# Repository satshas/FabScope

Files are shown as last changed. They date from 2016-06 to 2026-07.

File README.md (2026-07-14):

# Fab Scope

An easily fabbable and portable oscilloscope.

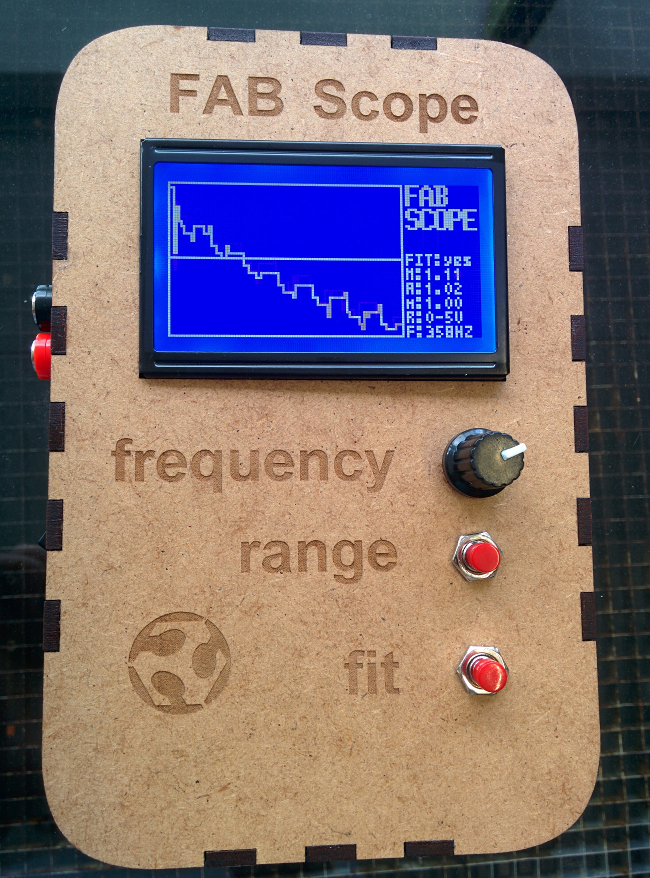
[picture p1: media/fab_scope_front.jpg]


Features
--

- 2 voltage range supported: 0-5V, 0-50V (DC only)
- button to change the voltage ranges and fit using interrupts
- supported sampling frequency: from 100HZ to 10KHZ
- adjustable sampling frequency using a potentiometer
- 128 x 64 graphic display
- embedded high voltage relays
- on/off switch
- plug and play probes
- portable (9V battery last for more than 8 hours)
- mdf and acrylic cases
- programmable using an FTDI
- voltage measurements: max, min, average
- fit function that will zoom exactly into the current signal range

Board
--

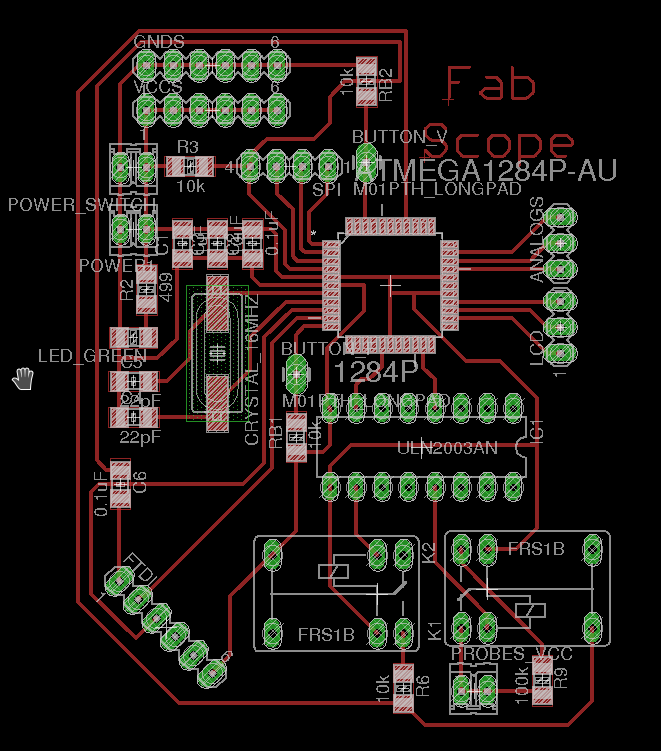
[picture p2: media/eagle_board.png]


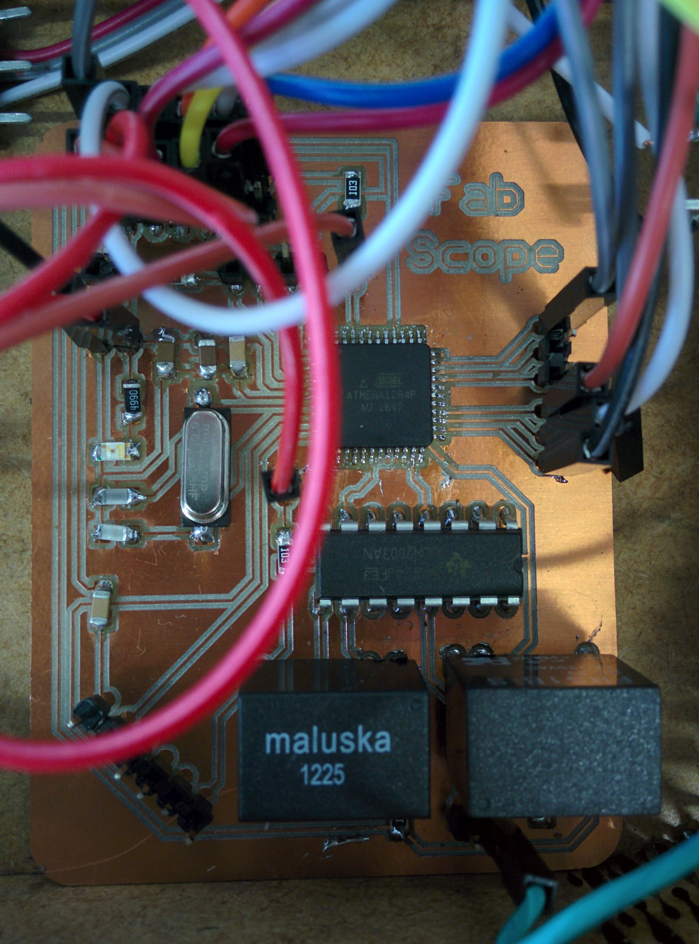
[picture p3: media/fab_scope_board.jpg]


- [Fab12 scope schematic](https://github.com/satshas/FabScope/raw/master/eagle/fab_scope.sch)
- [Fab12 scope board](https://github.com/satshas/FabScope/raw/master/eagle/fab_scope.brd)
- [Fab12 scope internal png](https://github.com/satshas/FabScope/raw/master/media/fab_scope_internal.png)
- [Fab12 scope cut png](https://github.com/satshas/FabScope/raw/master/media/fab_scope_cut.png)

Software
--

[download the code](https://raw.githubusercontent.com/satshas/FabScope/master/code/fab_scope/fab_scope.ino)

Media
--

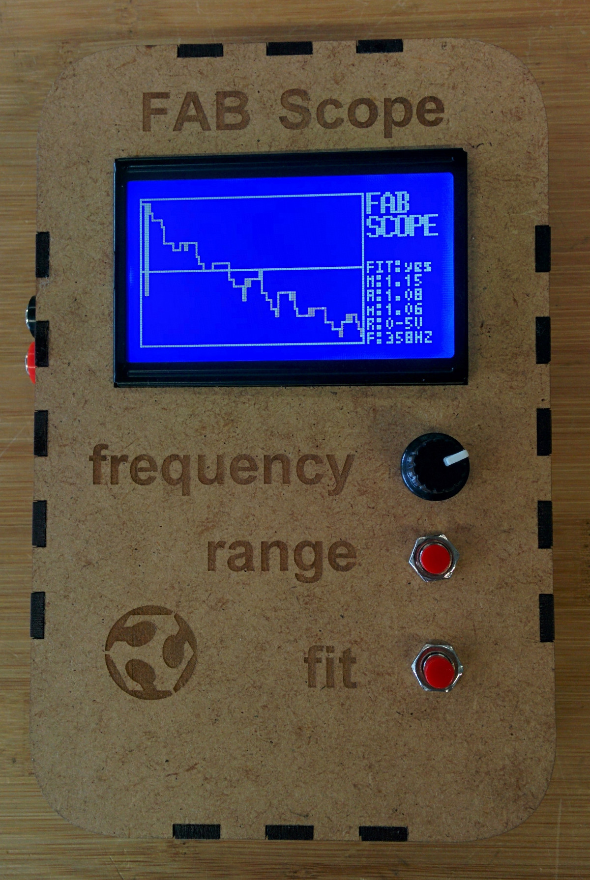
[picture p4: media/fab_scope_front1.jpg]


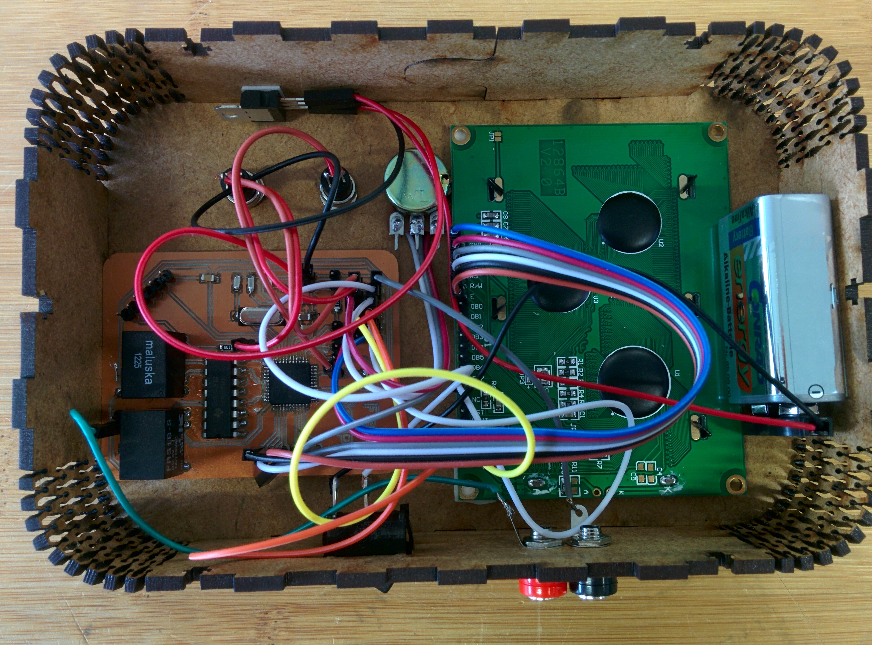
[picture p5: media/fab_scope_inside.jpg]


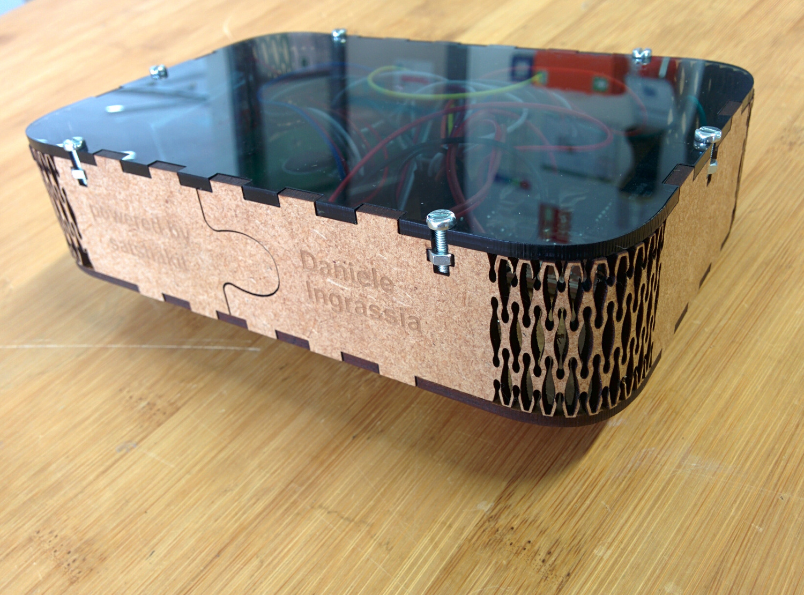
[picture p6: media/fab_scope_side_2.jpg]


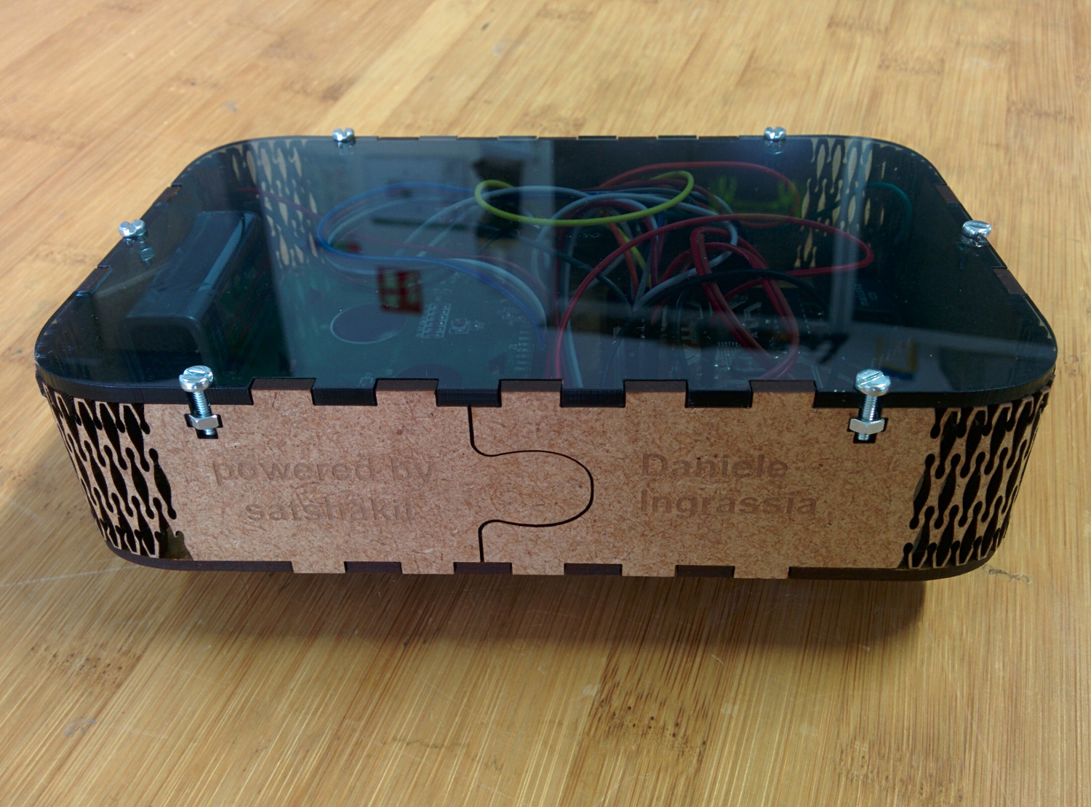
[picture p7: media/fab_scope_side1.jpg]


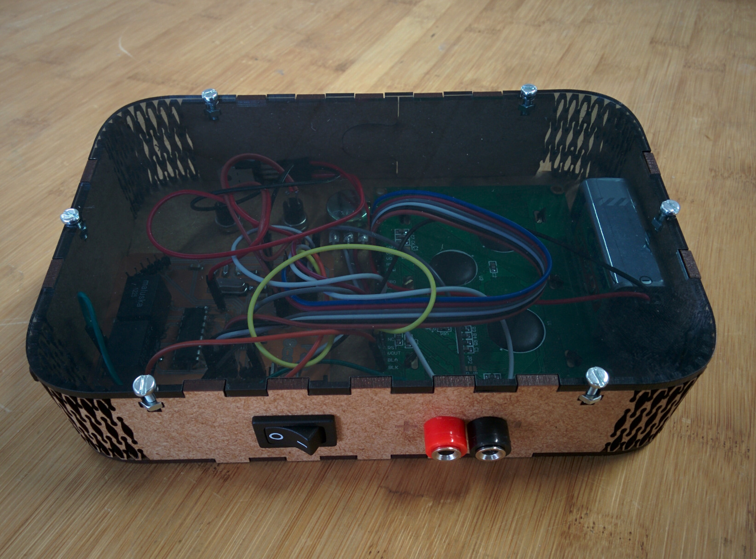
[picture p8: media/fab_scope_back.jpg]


Authors
--

- Daniele Ingrassia

Contact
--

- **ingrassiada@gmail.com**
- **[linkedin](http://it.linkedin.com/in/danieleingrassia)**

Thanks
--

[Fablab Kamp-Lintfort](http://fablab.hochschule-rhein-waal.de/index.php/de/)<br />
Hochschule Rhein-Waal<br />
Friedrich-Heinrich-Allee 25, 47475 Kamp-Lintfort, Germany<br />
fablab@hochschule-rhein-waal.de

License
--
This work is licensed under the terms of Attribution-ShareAlike 4.0 International ([CC BY-SA 4.0](https://creativecommons.org/licenses/by-sa/4.0/)).

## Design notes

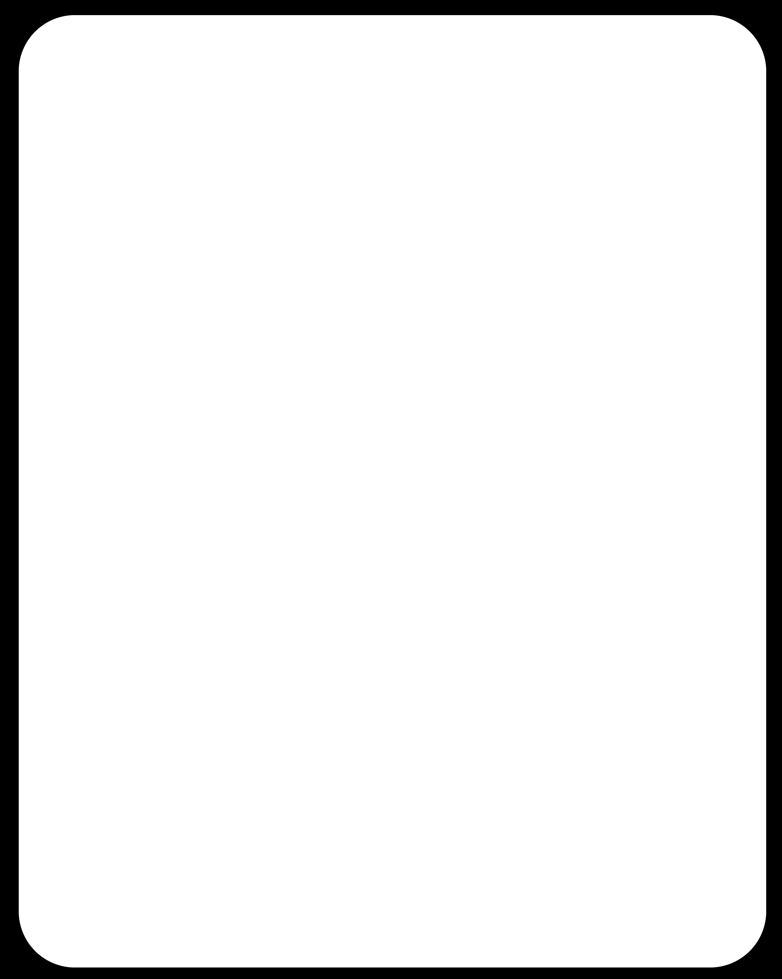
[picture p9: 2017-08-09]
media/fab_scope_cut.png

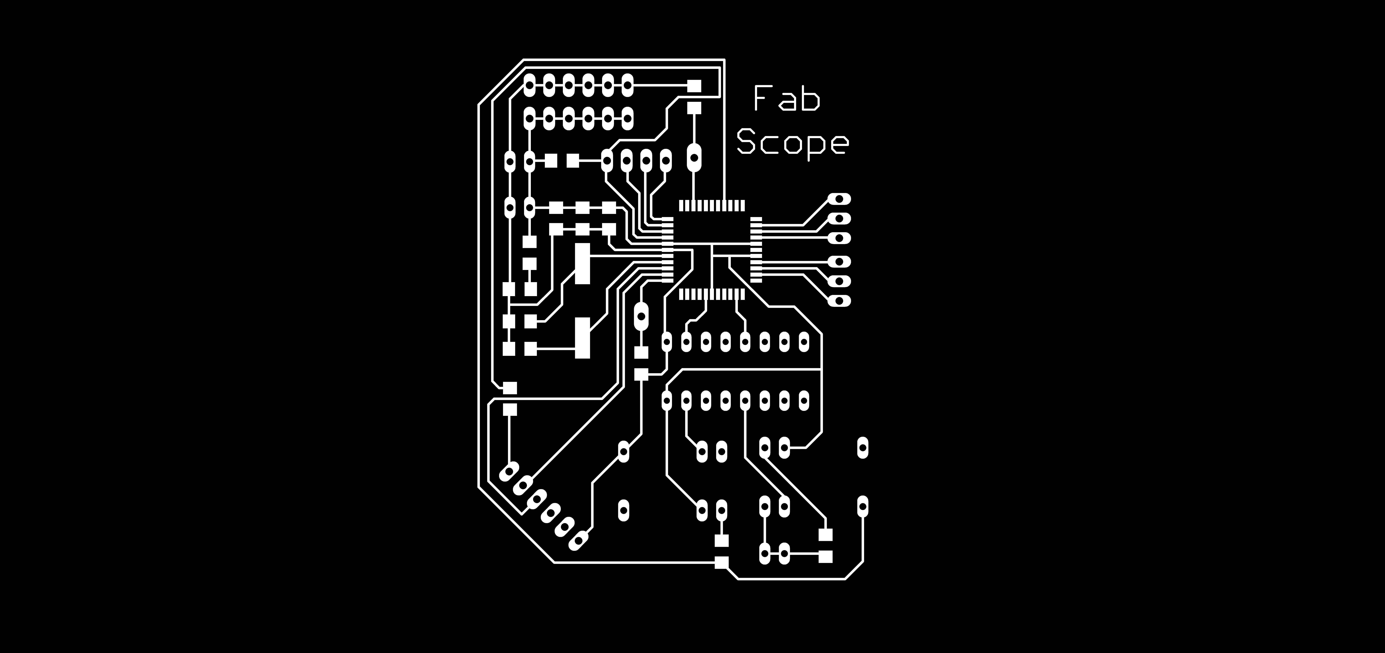
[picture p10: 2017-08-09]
media/fab_scope_all.png

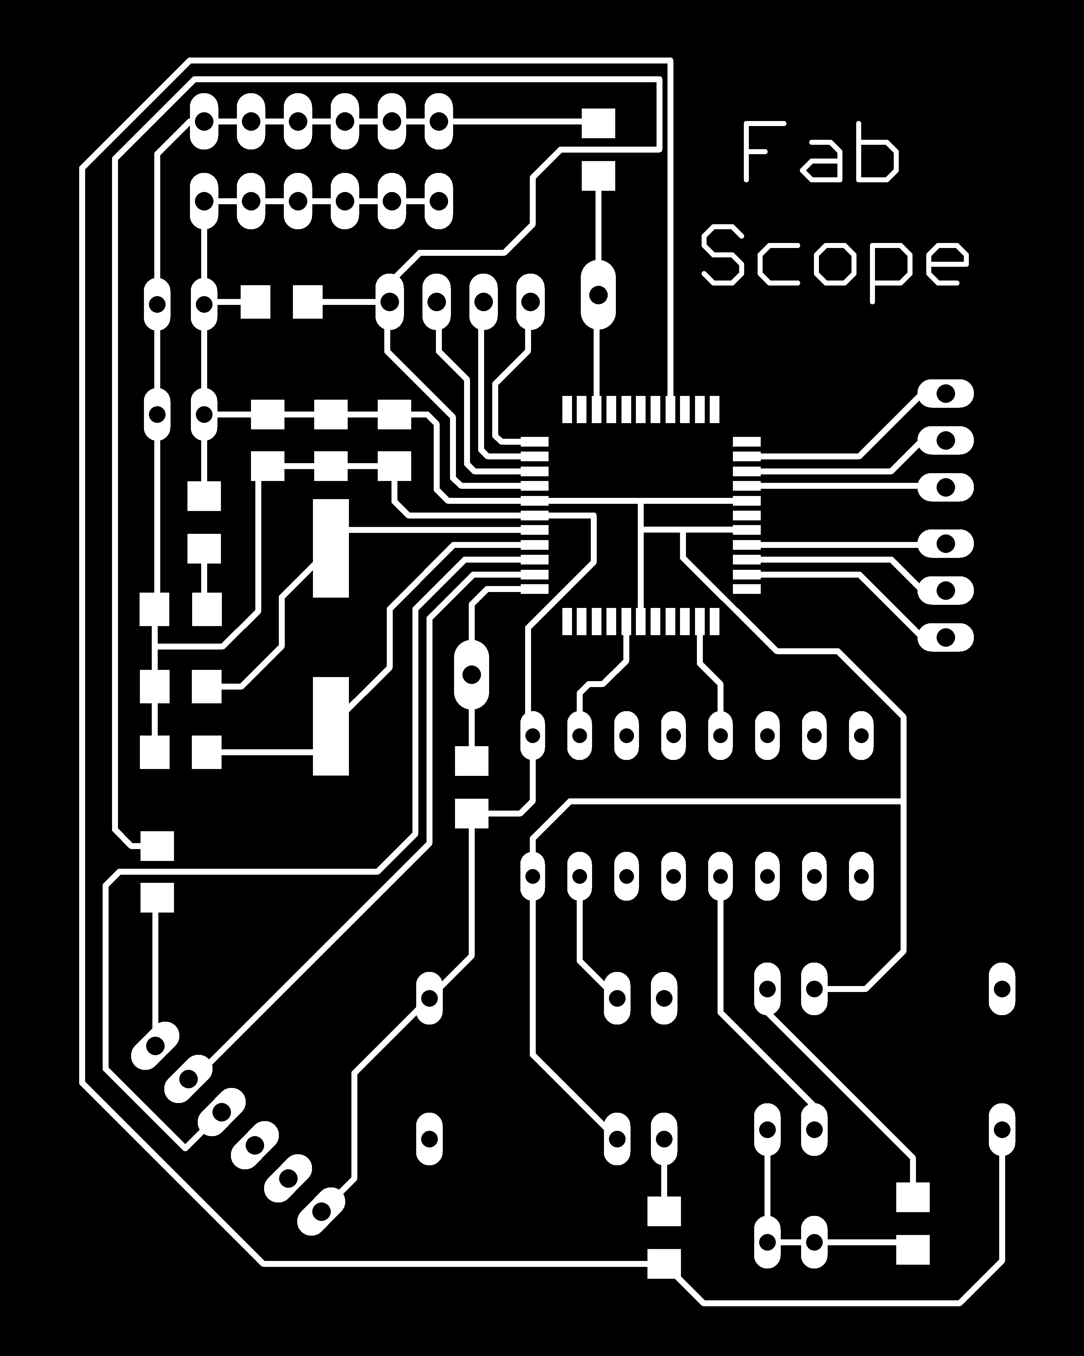
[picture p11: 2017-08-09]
media/fab_scope_internal.png

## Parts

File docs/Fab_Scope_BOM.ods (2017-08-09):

Value | Manufacturer Part No | Package | Description | FARNELL | Price € | Quantity | Min. Quantity Cost €
- | ATMEGA1284P-AU | TQFP-44 | microcontroller | Aliexpress (http://it.farnell.com/atmel/atmega1284p-au/mcu-8bit-atmega-20mhz-tqfp-44/dp/1715480) | 3.47 | 1 | 3.47
16Mhz/18pF | MCRSD16000F183000RR | SMD 11.4 x 4.7 mm | crystal | FARNELL (http://it.farnell.com/multicomp/mcrsd16000f183000rr/crystal-16mhz-18pf-hc49-us-smd/dp/2395958) | 0.20 | 1 | 0.20
10K | ERJ8GEYJ103V | 1206 | resistor | FARNELL (http://it.farnell.com/panasonic-electronic-components/erj8geyj103v/resistore-1206-10k-5-0-25w/dp/2057856) | 0.03 | 8 | 0.26
22pF | MC1206N220J500CT | 1206 | capacitor | FARNELL (http://it.farnell.com/multicomp/mc1206n220j500ct/condens-mlcc-c0g-np0-22pf-50v/dp/2320891) | 0.05 | 2 | 0.47
10uF | MC1206X106K250CT | 1206 | capacitor | FARNELL (http://it.farnell.com/multicomp/mc1206x106k250ct/condensatore-mlcc-x5r-10uf-25v/dp/2112753) | 0.15 | 1 | 0.15
1uF | MC1206F105Z500CT | 1206 | capacitor | FARNELL (http://it.farnell.com/multicomp/mc1206f105z500ct/condensatore-mlcc-y5v-1uf-50v/dp/1759455) | 0.06 | 1 | 0.63
100nF | MC1206B104K500CT | 1206 | capacitor | FARNELL (http://it.farnell.com/multicomp/mc1206b104k500ct/condensatore-mlcc-x7r-100nf-50v/dp/1759361) | 0.04 | 2 | 0.35
green | MCL-S250GC | 1206 | green led | FARNELL (http://it.farnell.com/multicomp/mcl-s250gc/led-smd-1206-verde/dp/1581232) | 0.12 | 1 | 0.60
499 | CRCW1206499RFKEA | 1206 | resistor | FARNELL (http://it.farnell.com/vishay-draloric/crcw1206499rfkea/resistor-1206-499r-1/dp/1470020) | 0.03 | 1 | 0.28
100k | MC0125W12061100K | 1206 | resistor | FARNELL (http://it.farnell.com/multicomp/mc0125w12061100k/res-film-spesso-100k-1-0-125w/dp/9335773) | 0.0035 | 1 | 0.04
499k | MC0063W06031499K | 1206 | resistor | FARNELL (http://it.farnell.com/multicomp/mc0063w06031499k/res-film-spesso-499k-1-0-063w/dp/1171055) | 0.0013 | 2 | 0.01
pin header | 61304011021 | 2.54 mm | pin header | FARNELL (http://it.farnell.com/wurth-elektronik/61304011021/header-2-54mm-pin-tht-r-a-40way/dp/2356192) | 1.77 | 1 | 1.77
pin header | M20-9990246 | 2.54 mm | pin header | FARNELL (http://it.farnell.com/harwin/m20-9990246/header-diritta-2-54mm-1row-bifase/dp/1022247) | 0.07 | 2 | 0.65
LCD display | 12864 V2.0 | - | LCD display | Aliexpress (https://www.aliexpress.com/item/128-64-DOTS-LCD-module-5V-blue-screen-12864-LCD-with-backlight-ST7920-Parallel-port/32464276214.html) | 5.53 | 1 | 5.53
driver | ULN2003A | - | darlington array | FARNELL (http://it.farnell.com/stmicroelectronics/uln2003a/darlington-array-7npn-2003-dip16/dp/1094421) | 0.52 | 1 | 0.52
relay | FRS1B-S | - | 5V relay | EBAY (http://www.ebay.de/itm/Relais-MALUSKA-FRS1B-S-24-V-1-Wechsler-340570-/142289295972) | 1 | 2 | 2
push button | SPST-NO Button | - | SPST-NO push button | EBAY (http://www.ebay.it/itm/251383502767?var=550311934053&ssPageName=STRK%3AMEBIDX%3AIT) | 1.19 | 2 | 2.38
10k | B10K |  | 10K potentiometer | EBAY (http://www.ebay.de/itm/1x-Lineares-Drehpotentiometer-10-k-Potentiometer-Potenziometer-B10K-/292161587681) | 2 | 1 | 2
MDF | - | - | 3mm MDF wood (50x70cm) | - | - | - | -
acrylic | - | - | 3mm acrylic (15x20cm) | - | - | - | -
wires | - | - | various 0.14mm wires | - | - | - | -
double side scotch tape |  |  | double side mounting scotch tape | - | - | - | -
nuts and bolts |  |  | 6xM3 10mm and 6xM3 nuts | - | - | - | -
5V voltage reg | 7805 |  | step up/step down voltage regulator | FARNELL (http://de.farnell.com/fairchild-semiconductor/lm7805ct/v-reg-5-0v-7805-to-220-3/dp/1696994) | 0.658 | 1 | 0.658
banana plug | - | - | banana plug | HOBBY KING (http://www.hobbyking.com/hobbyking/store/__74597__XT30_charge_lead_with_4mm_banana_plugs_AR_Warehouse_.html) | 1.91 | 1 | 1.91
FR2/FR4 copper sheet | - | - | single side 100x160mm | - | - | 1 | -
cyanoacrylate glue | - | - | standard cyano glue (SuperGlue/Attack) | - | - | - | -
 |  |  |  |  |  |  | Total cost
 |  |  |  |  |  |  | 23.886

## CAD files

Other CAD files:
design/Fab_Scope.3dm

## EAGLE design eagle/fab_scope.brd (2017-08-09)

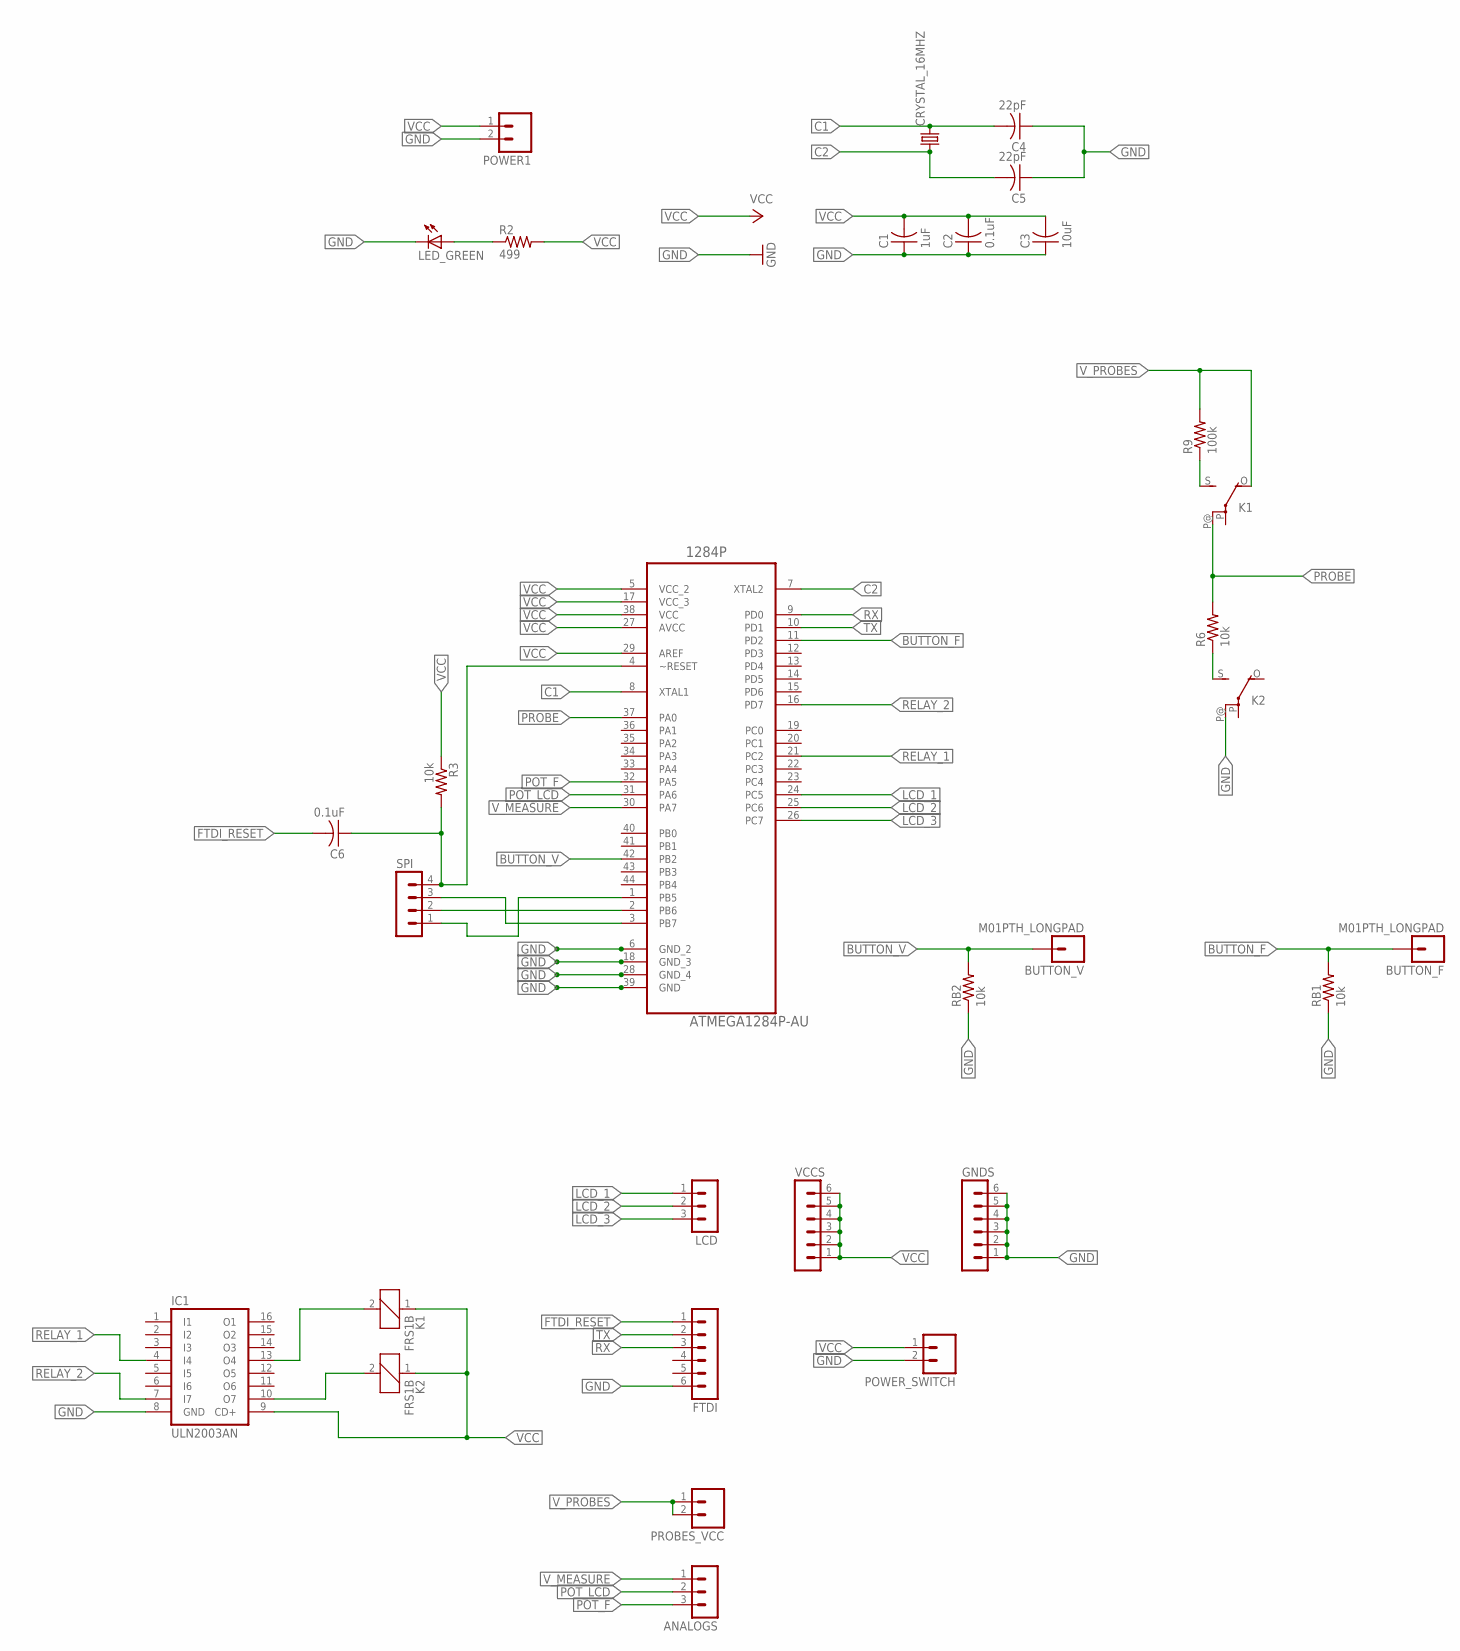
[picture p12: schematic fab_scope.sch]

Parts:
1284P: ATMEGA1284P-AU; QFP80P1200X1200X120-44N
ANALOGS: MA03-1
BUTTON_F: M01PTH_LONGPAD; 1X01_LONGPAD
BUTTON_V: M01PTH_LONGPAD; 1X01_LONGPAD
C1: 1uF; C1206
C2, C6: 0.1uF; C1206
C3: 10uF; C1206
C4, C5: 22pF; C1206
CRYSTAL_16MHZ: CRYSTALHC49UP; HC49UP
FTDI: MA06-1
GNDS: MA06-1
IC1: ULN2003AN; DIL16
K1, K2: FRS1B
LCD: MA03-1
LED_GREEN: LED1206; 1206
POWER1: M02; 02P
POWER_SWITCH: M02; 02P
PROBES_VCC: M02; 02P
R2: 499; R1206
R3, R6: 10k; R1206
R9: 100k; R1206
RB1, RB2: 10k; R1206
SPI: MA04-1
VCCS: MA06-1

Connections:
BUTTON_F: 1284P.11 (PD2), BUTTON_F.1, RB1.2
BUTTON_V: 1284P.42 (PB2), BUTTON_V.1, RB2.2
C1: 1284P.8 (XTAL1), C4.2, CRYSTAL_16MHZ.2
C2: 1284P.7 (XTAL2), C5.2, CRYSTAL_16MHZ.1
FTDI_RESET: C6.2, FTDI.1
GND: 1284P.6 (GND_2), C1.1, C2.1, C3.1, C4.1, C5.1, FTDI.6, GNDS.1, GNDS.2, GNDS.3, GNDS.4, GNDS.5, GNDS.6, IC1.8 (GND), K2.P@, LED_GREEN.2 (C), POWER1.2, POWER_SWITCH.2, RB1.1, RB2.1
LCD_1: 1284P.24 (PC5), LCD.1
LCD_2: 1284P.25 (PC6), LCD.2
LCD_3: 1284P.26 (PC7), LCD.3
unnamed: IC1.10 (O7), K2.2
unnamed: IC1.13 (O4), K1.2
unnamed: K2.S, R6.1
unnamed: K1.S, R9.1
unnamed: 1284P.3 (PB7), SPI.3
unnamed: 1284P.2 (PB6), SPI.2
unnamed: 1284P.1 (PB5), SPI.1
unnamed: 1284P.4 (~RESET), C6.1, R3.2, SPI.4
unnamed: LED_GREEN.1 (A), R2.1
POT_F: 1284P.32 (PA5), ANALOGS.3
POT_LCD: 1284P.31 (PA6), ANALOGS.2
PROBE: 1284P.37 (PA0), K1.P@, R6.2
RELAY_1: 1284P.21 (PC2), IC1.4 (I4)
RELAY_2: 1284P.16 (PD7), IC1.7 (I7)
RX: 1284P.9 (PD0), FTDI.3
TX: 1284P.10 (PD1), FTDI.2
VCC: 1284P.5 (VCC_2), 1284P.17 (VCC_3), 1284P.27 (AVCC), 1284P.29 (AREF), C1.2, C2.2, C3.2, IC1.9 (CD+), K1.1, K2.1, POWER1.1, POWER_SWITCH.1, R2.2, R3.1, VCCS.1, VCCS.2, VCCS.3, VCCS.4, VCCS.5, VCCS.6
V_MEASURE: 1284P.30 (PA7), ANALOGS.1
V_PROBES: K1.O, PROBES_VCC.1, PROBES_VCC.2, R9.2

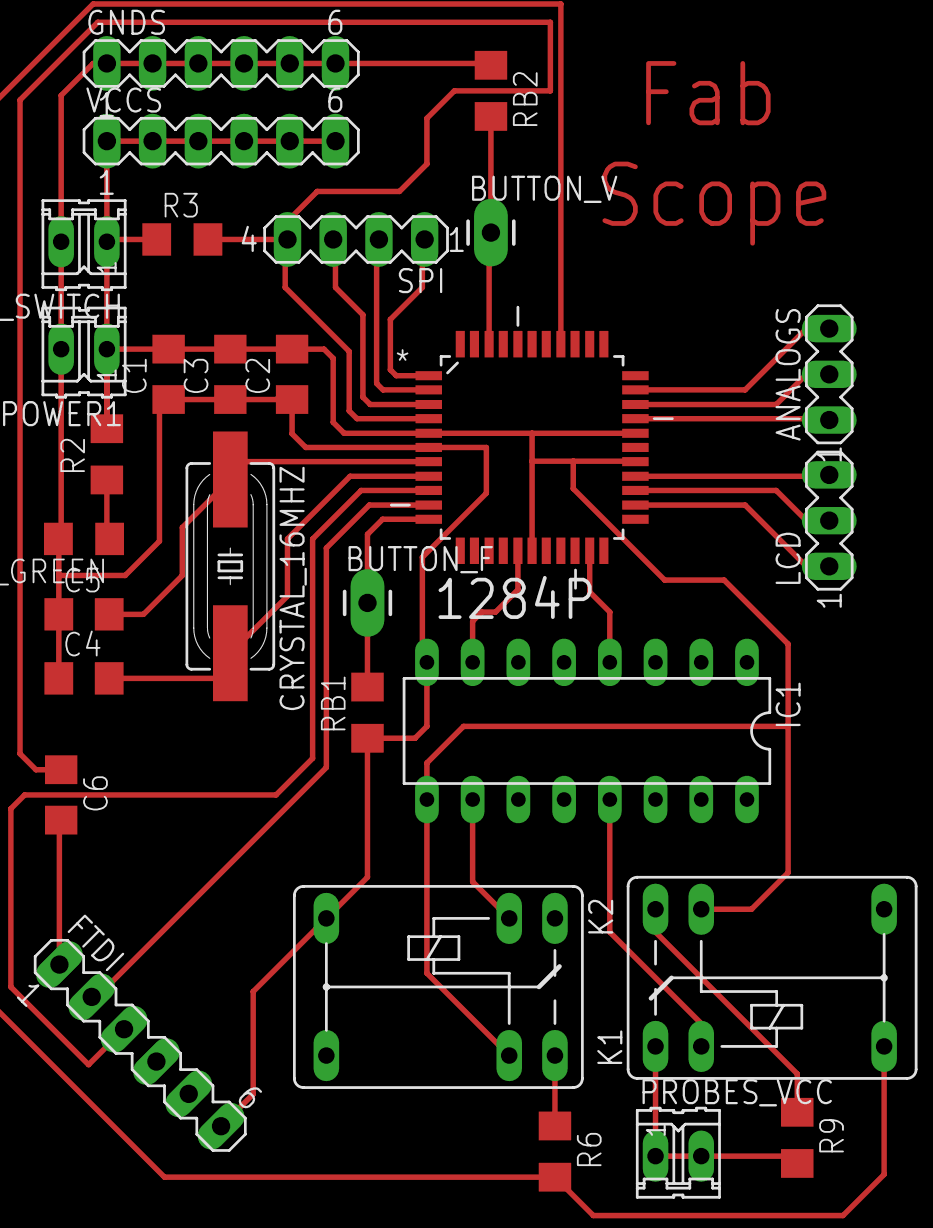
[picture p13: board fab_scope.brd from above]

Board: 2 copper layers, 29 parts (0 on the bottom side), 28 nets.

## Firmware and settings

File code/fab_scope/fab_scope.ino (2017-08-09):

#include "U8glib.h"

#define SIGNAL_FRAME_H 64
#define SIGNAL_FRAME_W 96
#define SIGNAL_FRAME_PROBED 94
#define PROBE_PIN A0
#define SAMPLING_RATE_PIN A5
#define BUTTON_VOLTAGE_RANGE 2
#define BUTTON_FIT 10

#define RELAY_K1_PIN 15
#define RELAY_K2_PIN 18

//#define RELAY_K3_PIN 15
//#define RELAY_K4_PIN 16
//#define RELAY_K5_PIN 17
//#define RELAY_K6_PIN 18

#define MINIMUM_DISPLAY_SIGNAL_HEIGHT 3
#define MAXIMUM_DISPLAY_SIGNAL_HEIGHT 61

uint16_t minimumAnalogRead;
uint16_t maximumAnalogRead;

#define MINIMUM_ANALOG_READ 0
#define MAXIMUM_ANALOG_READ 1023

#define BUTTON_RANGE_TIME_PRESS_AGAIN 1000

//#define SAMPLING_RATE_MAX_MICROSECONDS 100000
#define SAMPLING_RATE_MAX_MICROSECONDS 10000
#define SAMPLING_RATE_MIN_MICROSECONDS 100

const bool DEBUG  = true;

char freqPrint[9];
char voltagePrint[8];
char voltageRangePrint[9];
bool fitFunction;
long probeRate;
float probeRateMillis;
uint16_t probe1Valuea, maxVoltageProbe, minVoltageProbe;
long avgVoltageProbe;
uint16_t probedValues[SIGNAL_FRAME_PROBED];
uint8_t C,Z,probedValuesCounter;
uint8_t currentRange;
long buttonRangeTimePressed1,buttonRangeTimePressed2;
double samplingFrequency;
double maxVoltage,minVoltage,avgVoltage;
double currentVoltageRatio;
const double voltageRatio5 = 0.00497512437811; //volts per unit
const double voltageRatio50 = 0.05681818181818;//volts per unit
const double voltageRatio120 = 0.15151515151515;//volts per unit
const double voltageRatio200 = 0.38461538461538;//volts per unit

U8GLIB_ST7920_128X64 u8g(23, 21, 22, U8G_PIN_NONE);

void setup(void) {
  
  //debug init
   if(DEBUG)
    Serial.begin(9600);

  fitFunction = false;
  minimumAnalogRead = 0;
  maximumAnalogRead = 1023;
    
  //analog input init
  pinMode(PROBE_PIN,INPUT);
  pinMode(SAMPLING_RATE_PIN,INPUT);

  //digital relay pins init
  pinMode(RELAY_K1_PIN,OUTPUT);
  pinMode(RELAY_K2_PIN,OUTPUT);
  //pinMode(RELAY_K3_PIN,OUTPUT);
  //pinMode(RELAY_K4_PIN,OUTPUT);
  //pinMode(RELAY_K5_PIN,OUTPUT);
  //pinMode(RELAY_K6_PIN,OUTPUT);

  //init time vars
  buttonRangeTimePressed1 = 0;
  buttonRangeTimePressed2 = 0;

  //digital button pin inputs
  pinMode(BUTTON_VOLTAGE_RANGE,INPUT);
  pinMode(BUTTON_FIT,INPUT);
 
  //other settings & init
  probeRate = 20;
  probedValuesCounter = 0;
   
  //display init
  u8g.setColorIndex(1);

  //default position at maximum voltage
  switch_5();

  //attach interrupts for changing the voltage range
  attachInterrupt(digitalPinToInterrupt(BUTTON_VOLTAGE_RANGE), interruptFunctionRange, HIGH);

  //attach interrupts for changing the fit button
  attachInterrupt(digitalPinToInterrupt(BUTTON_FIT), interruptFunctionFit, HIGH);
 
  if(DEBUG)
    Serial.println("init ok");
 
}

void loop(void) {

  /*if(digitalRead(BUTTON_FIT)){

    if(DEBUG)
      Serial.println("buttonFit");

      if(fitFunction)
        fitFunction = false;
    else
      fitFunction = true;
    
  }*/
  
  //do a complete probe and then refresh the screen
  //this is needed because the resfresh rate of the display is to slow

  //first calculate the probe rate according to the position of the potentiometer
  probeRate = analogRead(SAMPLING_RATE_PIN);
  probeRate = map(probeRate,MINIMUM_ANALOG_READ,MAXIMUM_ANALOG_READ,SAMPLING_RATE_MIN_MICROSECONDS,SAMPLING_RATE_MAX_MICROSECONDS);
  samplingFrequency = probeRate;
  probeRateMillis = probeRate/1000;
  samplingFrequency = 1/(samplingFrequency*0.000001);
 
  if(DEBUG)
    Serial.println(samplingFrequency);

  //now start to fill the data buffer with samples
  //reset the voltage statistics
  maxVoltageProbe = 0;
  minVoltageProbe=1500;
  avgVoltageProbe = 0;
  
  Z=0;
  
  while(true){

      //place this inside an interrupt or outside the for
      //of just simplyfy the loop and consider the time of the analog read
      probedValues[Z] = analogRead(PROBE_PIN);
        
      //wait a certain amount of time according to the sampling rate
      if(probeRate<1000 && probeRate>=SAMPLING_RATE_MIN_MICROSECONDS)
        delayMicroseconds(probeRate-100);//consider the analog read
      else
        delay(probeRateMillis);//here not consider the analogRead delay

        ++Z;
        if(Z==SIGNAL_FRAME_PROBED)
          break;
           
  }

  //read only the voltage statistics
  Z=0;
  
  for(;Z<SIGNAL_FRAME_PROBED;Z++){
            
      //do statistics about the voltage
      
      if(probedValues[Z] > maxVoltageProbe)
        maxVoltageProbe = probedValues[Z];
      
      if( probedValues[Z] < minVoltageProbe)
        minVoltageProbe = probedValues[Z];

      avgVoltageProbe += probedValues[Z];
          
  }

  //check the fit function
  if(fitFunction){

    minimumAnalogRead = minVoltageProbe;
    maximumAnalogRead = maxVoltageProbe;
    
  }else{

   minimumAnalogRead = MINIMUM_ANALOG_READ;
   maximumAnalogRead = MAXIMUM_ANALOG_READ;
    
  }

  Z=0;
  
  for(;Z<SIGNAL_FRAME_PROBED;Z++)          
      probedValues[Z] = map(probedValues[Z],minimumAnalogRead,maximumAnalogRead,MINIMUM_DISPLAY_SIGNAL_HEIGHT,MAXIMUM_DISPLAY_SIGNAL_HEIGHT);
          
  if(DEBUG){

      Serial.print("max probe: ");
      Serial.println(maxVoltageProbe);
      Serial.print("min probe: ");
      Serial.println(minVoltageProbe);
      Serial.print("voltage ratio: ");
      Serial.println(currentVoltageRatio,15);

      Serial.print("avg sum: ");
      Serial.println(avgVoltageProbe);
     
  }

  //depends on the range selected you can have different ratio to obtain the real voltages values
  maxVoltage = currentVoltageRatio*maxVoltageProbe;
  minVoltage = currentVoltageRatio*minVoltageProbe;
  avgVoltage = currentVoltageRatio*avgVoltageProbe;

  //here divide to have the average
  avgVoltage = avgVoltage / SIGNAL_FRAME_W;

  if(DEBUG){

      Serial.print("max voltage: ");
      Serial.println(maxVoltage);
      Serial.print("min voltage: ");
      Serial.println(minVoltage);
     
  }
  
  u8g.firstPage();

  do{
 
    draw();

  }while( u8g.nextPage() );

 
}

void draw(void) {

  //setup the signal display
  u8g.drawFrame(0,0,SIGNAL_FRAME_W,SIGNAL_FRAME_H);
  u8g.drawLine(0,(SIGNAL_FRAME_H/2)-1,SIGNAL_FRAME_W-1,(SIGNAL_FRAME_H/2)-1);

  u8g.setFont(u8g_font_6x13B);
  u8g.drawStr(SIGNAL_FRAME_W+1, 9, "FAB");
  u8g.drawStr(SIGNAL_FRAME_W+1, 19, "SCOPE");

  //set micro size for all the text on the side
  u8g.setFont(u8g_font_micro);

  //draw selected voltage range
  u8g.drawStr(SIGNAL_FRAME_W+1, 58, voltageRangePrint);
  
  //draw fequency
  memset(freqPrint,'\0',9);
  dtostrf(samplingFrequency,5,0,freqPrint);
  
  if(samplingFrequency == SAMPLING_RATE_MAX_MICROSECONDS){

      freqPrint[0] = 'F';
      freqPrint[1] = ':';
      freqPrint[2] = '1';
      freqPrint[3] = '0';
      freqPrint[4] = 'K';
      freqPrint[5] = 'H';
      freqPrint[6] = 'Z';
   
  }else
  if(samplingFrequency >= 1000 && samplingFrequency < SAMPLING_RATE_MAX_MICROSECONDS){

      freqPrint[3] = freqPrint[2];
      freqPrint[2] = '.';
      freqPrint[4] = 'K';
      freqPrint[5] = 'H';
      freqPrint[6] = 'Z';

      //slide the content of the array of one positions right
      freqPrint[8] = freqPrint[7];
      freqPrint[7] = freqPrint[6];
      freqPrint[6] = freqPrint[5];
      freqPrint[5] = freqPrint[4];
      freqPrint[4] = freqPrint[3];
      freqPrint[3] = freqPrint[2];
      freqPrint[2] = freqPrint[1];

      //add the label:
      freqPrint[0] = 'F';
      freqPrint[1] = ':';
       
  }else{
   
    //write hz at the end
    freqPrint[5] = 'H';
    freqPrint[6] = 'Z';

     //add the label:
     freqPrint[0] = 'F';
     freqPrint[1] = ':';
   
    }

  //shift left the chars if there is space at the beginning
  while(freqPrint[0] == ' '){

      freqPrint[0] = freqPrint[1];
      freqPrint[1] = freqPrint[2];
      freqPrint[2] = freqPrint[3];
      freqPrint[3] = freqPrint[4];
      freqPrint[4] = freqPrint[5];
      freqPrint[5] = freqPrint[6];
      freqPrint[6] = ' ';
   
  }

  u8g.drawStr(SIGNAL_FRAME_W+1, 64, freqPrint);

  //print the statistic data
  memset(voltagePrint,'\0',8);
  dtostrf(minVoltage,5,2,voltagePrint);

  voltagePrint[8] = voltagePrint[7];
  voltagePrint[7] = voltagePrint[6];
  voltagePrint[6] = voltagePrint[5];
  voltagePrint[5] = voltagePrint[4];
  voltagePrint[4] = voltagePrint[3];
  voltagePrint[3] = voltagePrint[2];
  voltagePrint[2] = voltagePrint[1];
  voltagePrint[1] = ':';
  voltagePrint[0] = 'm';
  
  u8g.drawStr(SIGNAL_FRAME_W+1, 52, voltagePrint);

  memset(voltagePrint,'\0',8);
  dtostrf(avgVoltage,5,2,voltagePrint);

  voltagePrint[8] = voltagePrint[7];
  voltagePrint[7] = voltagePrint[6];
  voltagePrint[6] = voltagePrint[5];
  voltagePrint[5] = voltagePrint[4];
  voltagePrint[4] = voltagePrint[3];
  voltagePrint[3] = voltagePrint[2];
  voltagePrint[2] = voltagePrint[1];
  voltagePrint[1] = ':';
  voltagePrint[0] = 'A';

  u8g.drawStr(SIGNAL_FRAME_W+1, 46, voltagePrint);

  memset(voltagePrint,'\0',8);
  dtostrf(maxVoltage,5,2,voltagePrint);

  voltagePrint[8] = voltagePrint[7];
  voltagePrint[7] = voltagePrint[6];
  voltagePrint[6] = voltagePrint[5];
  voltagePrint[5] = voltagePrint[4];
  voltagePrint[4] = voltagePrint[3];
  voltagePrint[3] = voltagePrint[2];
  voltagePrint[2] = voltagePrint[1];
  voltagePrint[1] = ':';
  voltagePrint[0] = 'M';
  
  u8g.drawStr(SIGNAL_FRAME_W+1, 40, voltagePrint);

  //print the fit
  if(fitFunction)
    u8g.drawStr(SIGNAL_FRAME_W+1, 34, "FIT:yes");
  else
    u8g.drawStr(SIGNAL_FRAME_W+1, 34, "FIT:no");
    
  //draw signal data
  Z=0;
 
  for(;Z<SIGNAL_FRAME_W-2;Z++)
     
      if(probedValues[Z] > 0){

         if(Z>0){

          if(probedValues[Z] - probedValues[Z-1] > 1 || probedValues[Z] - probedValues[Z-1] < -1)
            u8g.drawLine(Z+1,(MAXIMUM_DISPLAY_SIGNAL_HEIGHT+2)-probedValues[Z-1],Z+1,(MAXIMUM_DISPLAY_SIGNAL_HEIGHT+2)-probedValues[Z]);
          else
            u8g.drawPixel(Z+1,(MAXIMUM_DISPLAY_SIGNAL_HEIGHT+2)-probedValues[Z]);
         
         }else
          u8g.drawPixel(Z+1,(MAXIMUM_DISPLAY_SIGNAL_HEIGHT+2)-probedValues[Z]);
       
   }
  
}

void switch_50(){
 
  digitalWrite(RELAY_K1_PIN,HIGH);
  digitalWrite(RELAY_K2_PIN,HIGH);
  //digitalWrite(RELAY_K3_PIN,HIGH);
  //digitalWrite(RELAY_K4_PIN,LOW);
  //digitalWrite(RELAY_K5_PIN,LOW);
  //digitalWrite(RELAY_K6_PIN,HIGH);

  memset(voltageRangePrint,'\0',9);

  voltageRangePrint[0] = 'R';
  voltageRangePrint[1] = ':';
  voltageRangePrint[2] = '0';
  voltageRangePrint[3] = '-';
  voltageRangePrint[4] = '5';
  voltageRangePrint[5] = '0';
  voltageRangePrint[6] = 'V';

  currentRange = 50;
  currentVoltageRatio = voltageRatio50;
 
}

void switch_5(){

  digitalWrite(RELAY_K1_PIN,LOW);
  digitalWrite(RELAY_K2_PIN,LOW);
  //digitalWrite(RELAY_K3_PIN,LOW);
  //digitalWrite(RELAY_K4_PIN,LOW);
  //digitalWrite(RELAY_K5_PIN,LOW);
  //digitalWrite(RELAY_K6_PIN,LOW);

  memset(voltageRangePrint,'\0',9);

  voltageRangePrint[0] = 'R';
  voltageRangePrint[1] = ':';
  voltageRangePrint[2] = '0';
  voltageRangePrint[3] = '-';
  voltageRangePrint[4] = '5';
  voltageRangePrint[5] = 'V'; 

  currentRange = 5;
  currentVoltageRatio = voltageRatio5;
 
}

/*
void switch_120(){

  digitalWrite(RELAY_K1_PIN,HIGH);
  digitalWrite(RELAY_K2_PIN,LOW);
  digitalWrite(RELAY_K3_PIN,LOW);
  digitalWrite(RELAY_K4_PIN,HIGH);
  digitalWrite(RELAY_K5_PIN,LOW);
  digitalWrite(RELAY_K6_PIN,LOW);

  memset(voltageRangePrint,'\0',9);

  voltageRangePrint[0] = 'R';
  voltageRangePrint[1] = ':';
  voltageRangePrint[2] = '0';
  voltageRangePrint[3] = '-';
  voltageRangePrint[4] = '1';
  voltageRangePrint[5] = '2';
  voltageRangePrint[6] = '0';
  voltageRangePrint[7] = 'V';

  currentRange = 120;
  currentVoltageRatio = voltageRatio120;
 
}
*/
/*
void switch_200(){

  digitalWrite(RELAY_K1_PIN,LOW);
  digitalWrite(RELAY_K2_PIN,HIGH);
  digitalWrite(RELAY_K3_PIN,LOW);
  digitalWrite(RELAY_K4_PIN,LOW);
  digitalWrite(RELAY_K5_PIN,HIGH);
  digitalWrite(RELAY_K6_PIN,LOW);

  memset(voltageRangePrint,'\0',9);

  voltageRangePrint[0] = 'R';
  voltageRangePrint[1] = ':';
  voltageRangePrint[2] = '0';
  voltageRangePrint[3] = '-';
  voltageRangePrint[4] = '2';
  voltageRangePrint[5] = '0';
  voltageRangePrint[6] = '0';
  voltageRangePrint[7] = 'V';

  currentRange = 200;
  currentVoltageRatio = voltageRatio200;
 
}
*/
void interruptFunctionRange(){

  buttonRangeTimePressed1 = millis();

  if((buttonRangeTimePressed1-buttonRangeTimePressed2) > BUTTON_RANGE_TIME_PRESS_AGAIN){
   
    if(currentRange == 5)
      switch_50();
//    else
//    if(currentRange == 50)
//      switch_120();
//    else
//    if(currentRange == 120)
//      switch_200();
     else
      switch_5();

    buttonRangeTimePressed2 = millis();
 
  }
 
}

void interruptFunctionFit(){

  if(fitFunction)
    fitFunction = false;
  else
    fitFunction = true;

    Serial.println("interruptFunctionFit");
  
}

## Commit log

2016-06-14 added images and code about the first prototype
    [Fab12_Oscilloscoppe_BOM.ods]
2016-06-22 added new scope version
    [fab12_oscilloscope.brd, fab12_oscilloscope.sch]
2016-06-22 updated bom
    [Fab12_Oscilloscoppe_BOM.ods]
2016-06-27 added design and updated bom
    [Fab12Scope.3dm, Fab12_Oscilloscoppe_BOM.ods]
2016-06-28 third prototype done
    [Fab12Scope.3dm, Fab12_Oscilloscoppe_BOM.ods]
2017-08-09 added new board and imgs
    [fab_scope.brd, fab_scope.sch]
2017-08-09 added media
    [Fab_Scope_BOM.ods]
2017-08-09 added bom and design
    [Fab12Scope.3dm, Fab_Scope.3dm, Fab_Scope_BOM.ods]

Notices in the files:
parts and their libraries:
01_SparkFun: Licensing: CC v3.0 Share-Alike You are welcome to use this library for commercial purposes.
